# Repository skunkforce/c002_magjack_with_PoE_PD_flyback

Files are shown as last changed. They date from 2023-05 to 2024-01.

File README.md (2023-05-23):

# edgy_board number c002
This design is part of the [edgy board project](https://github.com/skunkforce/edgy_boards). It provides a unified PoE flyback with magjack which can be added to c001 to provide a complete system. 

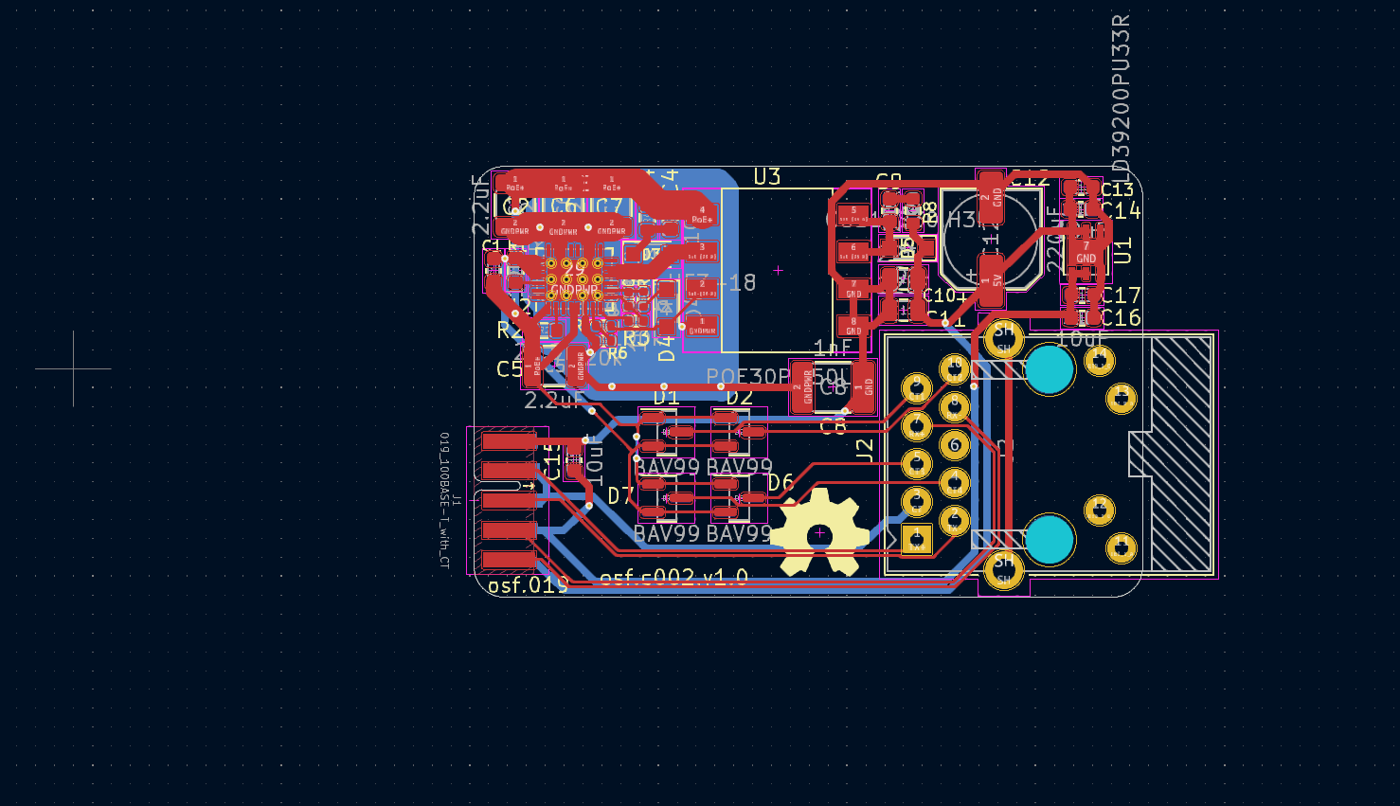
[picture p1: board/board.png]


# getting started
This repository uses submodules. After cloning use the command 

```$ git submodule update --init --recursive```

to pull the submodules before opening the project with kicad. 

# Tests
Tests can be found in [TESTS.md](TESTS.md)

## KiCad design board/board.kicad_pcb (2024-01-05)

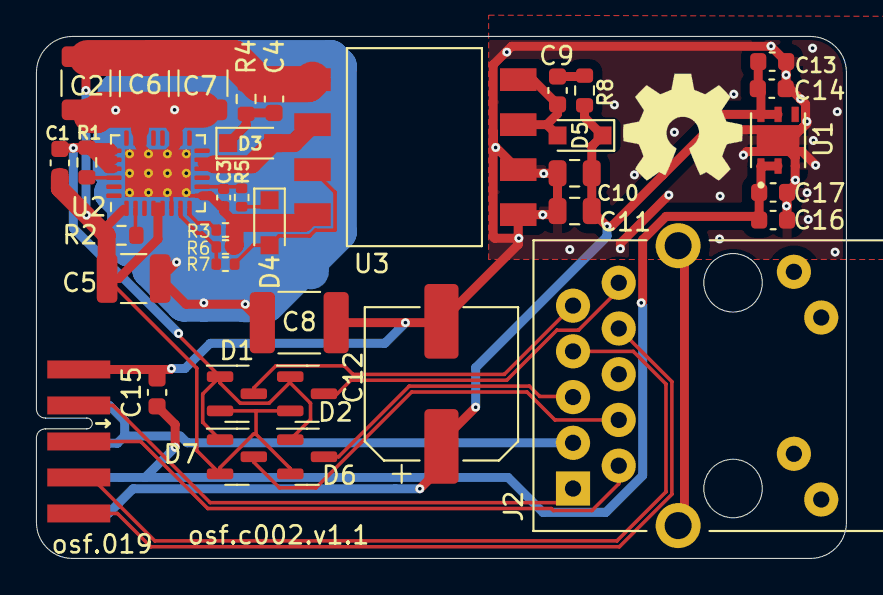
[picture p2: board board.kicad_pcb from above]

Board: 2 copper layers, 45.0 x 29.0 mm, 38 parts (0 on the bottom side), 26 nets.

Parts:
C1: 100nF; C_0603_1608Metric
C2, C5, C6, C7: 2.2uF; C_1210_3225Metric
C3: 100nF; C_0402_1005Metric
C4, C9: 10nF; C_0603_1608Metric
C8: 1nF; C_1812_4532Metric
C10, C11: 22uF; C_0805_2012Metric
C12: 220uF; CP_Elec_8x6.9
C13, C17: 1uF; C_0603_1608Metric
C14, C15, C16: 10uF; C_0603_1608Metric
D1, D2, D6, D7: BAV99; SOT-23
D3: BAV21WS-HE3-18; D_SOD-323_HandSoldering
D4: 1N4148; D_SOD-323_HandSoldering
D5: CUS15S30,H3F; D_SOD-323_HandSoldering
J1: 019_100BASE-T_with_CT; on_edge_2x05_device
J2: LPJ4265BDNL
LOGO1: Logo_Open_Hardware_Small; OSHW-Symbol_6.7x6mm_SilkScreen
R1: 41.2R; R_0603_1608Metric
R2: 24.9k; R_0603_1608Metric
R3: 316k; R_0402_1005Metric
R4: 10k; R_0603_1608Metric
R5: 5k; R_0402_1005Metric
R6: 20k; R_0402_1005Metric
R7: 121k; R_0402_1005Metric
R8: 20R; R_0603_1608Metric
U1: LD39200PU33R; SON95P300X300X100-7N
U2: MP8007; QFN-28-1EP_4x5mm_P0.5mm_EP2.65x3.65mm_ThermalVias
U3: POE30P-50L; Transformer_Coilcraft_POE30P

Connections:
/Controller/5V: C10.1, C11.1, C12.1, C13.1, C14.1, D5.1 (K), J1.10 (5V), R8.2, U1.5 (EN), U1.6 (IN)
/Controller/GNDPWR: C2.2, C3.2, C5.2, C6.2, C7.2, C8.2, R3.2, R6.1, U2.6 (MODE), U2.9 (AGND), U2.16 (GND), U2.17, U2.20 (RTN), U2.21, U2.29 (GND), U3.1 (B-)
/Controller/PoE+: C1.1, C2.1, C4.2, C5.1, C6.1, C7.1, D1.2 (A), D2.2 (A), D6.2 (A), D7.2 (A), R2.1, R4.2, U2.1 (AUX), U2.4 (VDD), U2.5 (FB2), U3.4 (P-)
/Controller/PoE-: C1.2, D1.1 (K), D2.1 (K), D6.1 (K), D7.1 (K), R1.2, U2.23 (VSS), U2.24, U2.25 (FTY)
/ldo/3.3v: C15.1, C16.1, C17.1, J1.9 (3.3V), U1.1 (OUT), U1.2 (SENSE)
/magjack/CT: J1.7 (CT1), J1.8 (CT2), J2.3 (CT)
/magjack/CT1: D1.3 (K), J2.9
/magjack/CT2: D2.3 (K), J2.10
/magjack/CT3: D6.3 (K), J2.5
/magjack/CT4: D7.3 (K), J2.4
/magjack/RX+: J1.4 (TD2+), J2.7 (RD+)
/magjack/RX-: J1.5 (TD2-), J2.8 (RD-)
/magjack/TX+: J1.2 (TD1+), J2.1 (TD+)
/magjack/TX-: J1.3 (TD1-), J2.2 (TD-)
GND: C8.1, C10.2, C11.2, C12.2, C13.2, C14.2, C15.2, C16.2, C17.2, J1.1 (GND), J1.6 (GND), U1.3 (GND), U1.7 (EXP), U3.7 (S2-), U3.8 (S-)
unnamed: C9.2, R8.1
unnamed: D3.2 (A), U2.12 (SW), U2.13, U3.3 (P+)
unnamed: C4.1, D3.1 (K), R4.1
unnamed: D4.2 (A), R7.1, U3.2 (B+)
unnamed: D4.1 (K), R5.1
unnamed: C9.1, D5.2 (A), U3.5 (S2+), U3.6 (S+)
unnamed: R1.1, U2.26 (CLASS)
unnamed: R2.2, U2.2 (DET)
unnamed: R6.2, R7.2, U2.7 (FB1)
unnamed: R3.1, U2.8 (ILIM)
unnamed: C3.1, R5.2, U2.10 (VCC)

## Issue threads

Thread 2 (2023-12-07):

D4 und C12 sind unklar

Hiwados, 2023-12-07:
Bei diesen beiden Bauteile habe ich keine genauen Information gefunden, bezüglich der Diode fehlt mir die MPN damit ich weiß wofür Sie ausgelegt sein soll. Und bei C12 fehlen mir angaben zur Toleranz und Spannungsfestigkeit.

NP199, 2023-12-21:
@odinthenerd

odinthenerd, 2023-12-21:
C12 angaben sind im schemetic zu finden

D4 angaben sind verbessert

Closed 2023-12-21.

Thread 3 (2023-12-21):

Problems during assembly

NP199, 2023-12-21:
We had some issues:
- U3 wrong footprint
- D4 wrong footprint or we used the wrong part. A datasheet would be great
- The rectifier is wrong and must be updated
- The buzzing of the flyback is pretty annoying

odinthenerd, 2023-12-21:
D4 is a generic part number, many companies produce these diodes with different MPNs and footprints. 1N4148WS or LCSC: C2128 should work.

U3 lol the coilcraft footrint does not match the coilcraft datasheet. footprint fixed in new version

rectifier: yeah that was stupid, I fixed it (we need to fix in a few other places)

buzzing: the ILIM resistor R3 needs to match the transformer, I changed its value as per the formula in the datasheet and now it doesn't buzz (its a miracle)

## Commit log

2023-05-28 cleaned up silkscreen
    [board.kicad_pcb]
2023-11-28 added LDO
    [Controller.kicad_sch, board.kicad_pcb, board.kicad_sch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]
2023-12-18 tuned ILIM resistor and voltage divider of flyback
    [Controller.kicad_sch, board.kicad_pcb, ldo.kicad_sch]
2023-12-20 made bulk cap footprint larger
    [Controller.kicad_sch, board.kicad_pcb]
2023-12-21 improved docs for D4
    [Controller.kicad_sch]
2024-01-05 added pours for LDO and LCSC parts
    [Controller.kicad_sch, board.kicad_pcb, rectifier.kicad_sch]
